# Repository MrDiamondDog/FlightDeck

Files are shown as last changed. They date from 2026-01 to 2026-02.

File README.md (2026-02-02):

# FlightDeck

Show your overhead flights in a nice and large LED matrix! Perfect addition to any room, especially to those nearby airports.

Additionally, the matrix will be able to display whatever you want in sleep/home states (when there are no flights), all customizable via a webserver hosted on the ESP, including displaying custom APIs!

I've seen a couple projects like this, and thought it would provide some nice experience to make my own, and it fits perfectly for Hack Club's Blueprint YSWS!

I haven't looked at any other similar projects, I want to build my own without copying others.

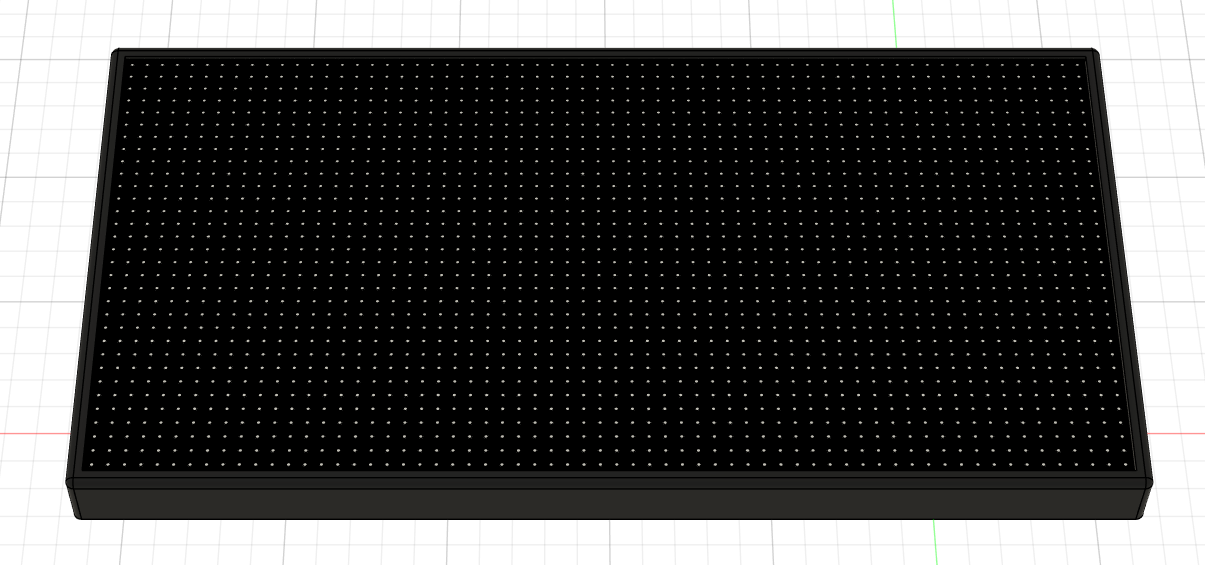
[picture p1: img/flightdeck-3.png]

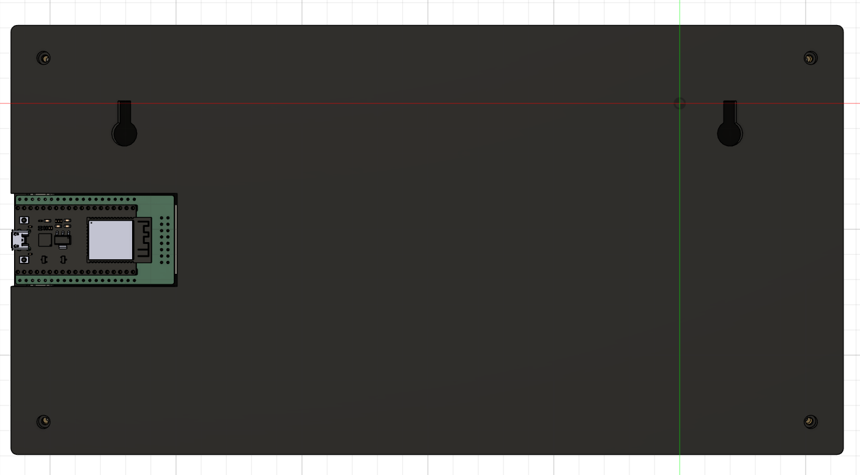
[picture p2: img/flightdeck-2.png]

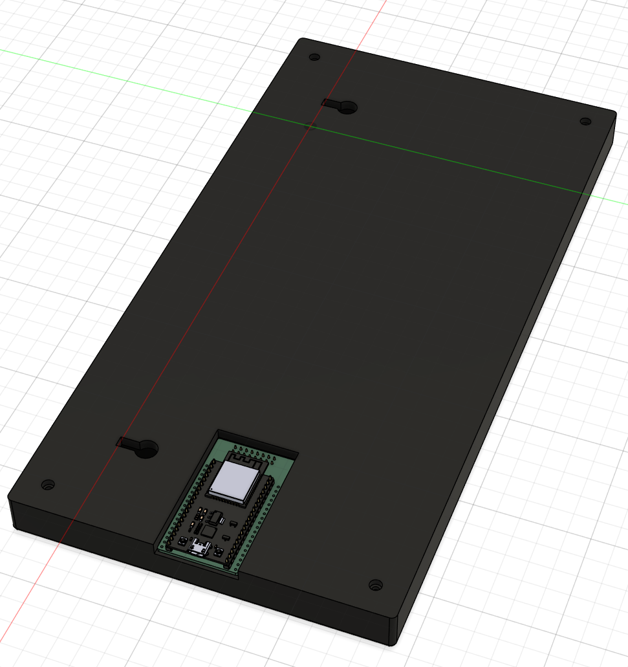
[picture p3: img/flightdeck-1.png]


## Hardware

A custom PCB is required for this project to connect the ESP dev board to the LED matrix.
All the gerber and KiCad files are in the `pcb` folder, and should run you about $5 on JLCPCB.

The rest of the hardware falls around $35 total on Aliexpress. See the [BOM](BOM) below.

- 64x32 RGB LED Matrix, 5mm pitch, 320x160mm ([Aliexpress](https://www.aliexpress.us/item/2251832185365664.html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))
- ESP32-DevKitC V4 Devboard ([Aliexpress](https://www.aliexpress.us/item/3256808703088919.html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))
- 2x8 Through-hole Female Pin Socket ([Aliexpress](https://www.aliexpress.us/item/3256803911413457.html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)) (only available in 10 pack) 
- 2.1mm Terminal Block Adapter ([Aliexpress](https://www.aliexpress.us/item/3256806569458868.html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](https://www.aliexpress.us/item/3256806079081322.html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))) (only in 5 pack)
- 5V 4A Barrel Jack Power Supply ([Aliexpress](https://www.aliexpress.us/item/3256807146253605.html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](https://www.aliexpress.us/item/3256806800927492.html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)))

### PCB

The PCB is pretty simple, just a bunch of holes for the ESP and HUB75 connector. 
There are extra holes along the ESP in case of emergency jumper wiring.

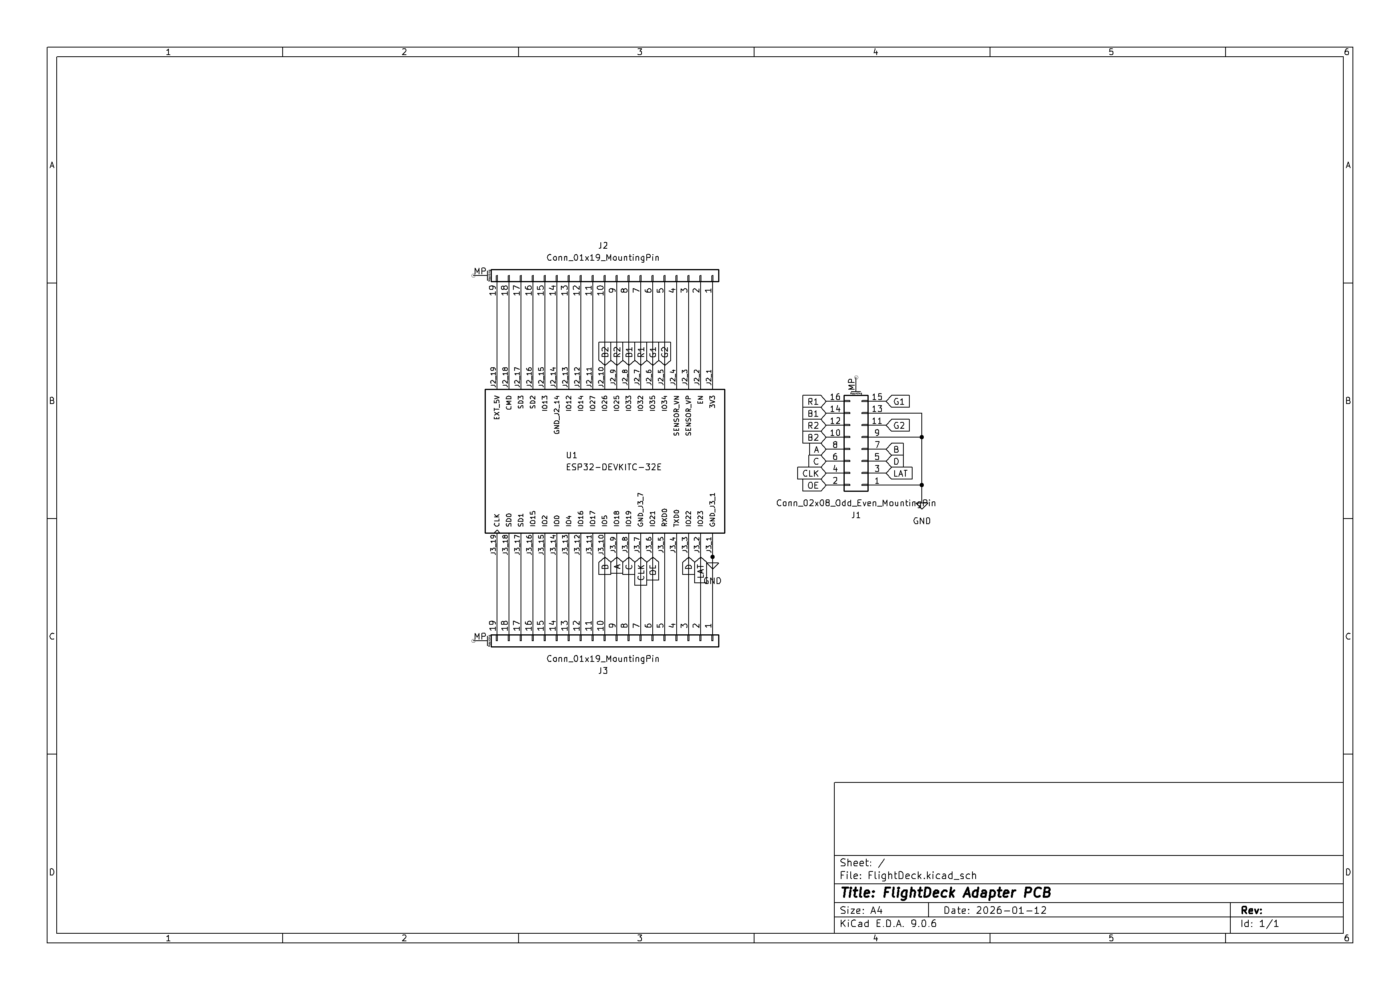
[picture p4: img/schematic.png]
PCB Schematic

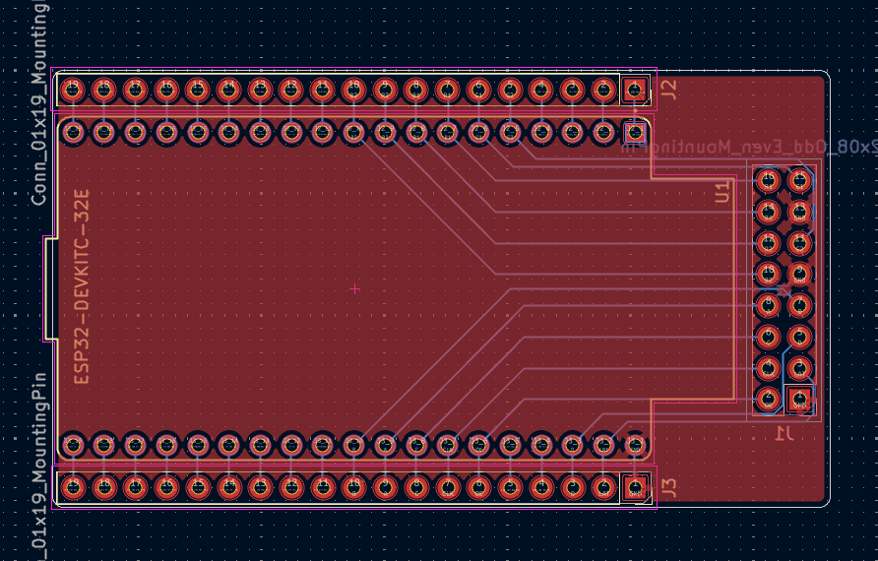
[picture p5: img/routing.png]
PCB Routing


### Wiring

1. Solder the dev board into the PCB. The PCB should have silkscreen text where you are putting the board. The USB should be hanging off the edge slightly.
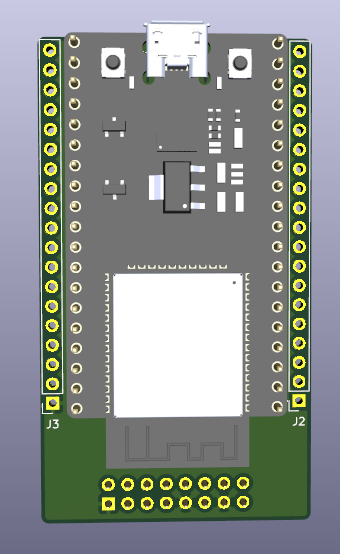
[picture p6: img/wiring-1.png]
Dev Board

2. Solder the pin connectors on the BACK of the PCB (opposite side of the dev board)
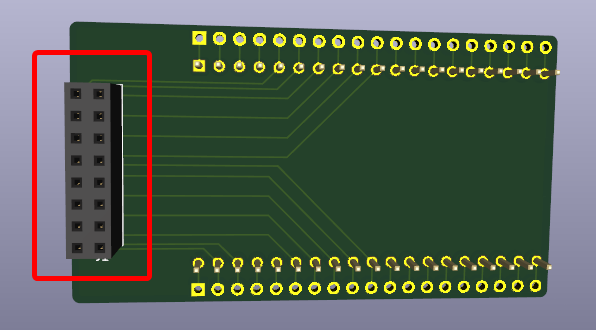
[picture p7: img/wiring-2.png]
Pin Connectors

3. Insert the PCB into the back of the LED matrix, making sure that the one you are plugging into is the INPUT (on the left), not the OUTPUT connector.
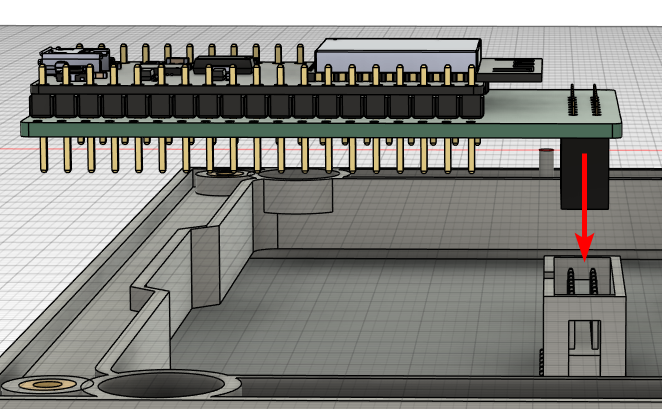
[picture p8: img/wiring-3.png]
Matrix

4. Connect the included power cables to the back of the LED matrix, then plug the U shaped ends into the (female) terminal block adapters, like so
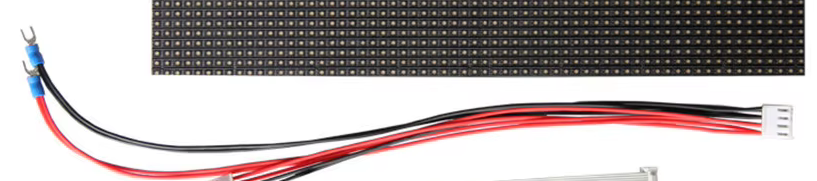
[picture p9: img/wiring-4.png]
Wires

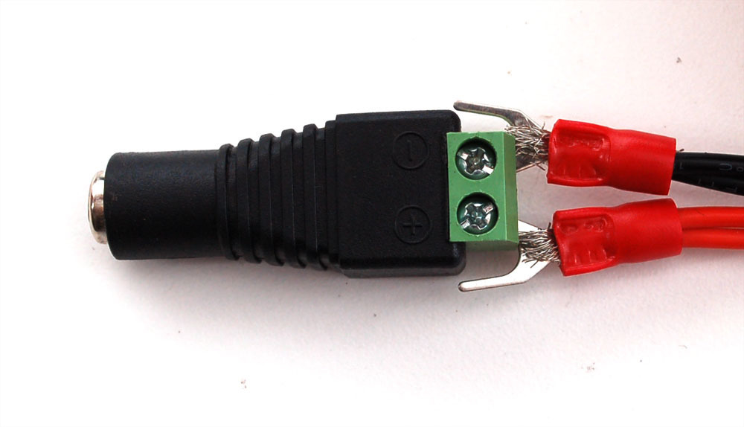
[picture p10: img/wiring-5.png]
Plug into adapter

5. Plug in your power supply to the adapter
6. Plug in micro USB to the esp

## Firmware

Programmed in CircuitPython, using the https://airlabs.co/ free live flight API. You may have to send them an email to get access. 

Make sure to rename the `settings.example.toml` file to `settings.toml` and fill in all the values.

TODO: There will be a webserver to customize the panel with, including custom sleep/home screens and custom API connections.

## BOM

**Please note: some of these items are only available in packs of 10 or 5, I could not find a cheaper alternative.**

| Name |Description | Link | Cost | Quantity | Total Price |
| ---- | --- | --- | --- | --- | --- |
| Factory P5 Indoor 320mmx160mm 16 Scan SMD Full Color Module 64x32 Pixels Dot Matrix Panel Video Screen Board | 64x32 LED Matrix | [Aliexpress](https://www.aliexpress.us/item/2251832185365664.html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) | $11.69 | 1 | $11.69 |
| ESP32-DevKitC V4 core board ESP32 development board All Types with ESP32-WROOM-32 32D 32U 32E WIFI+Bluetooth IoT NodeMCU-32 | ESP32-DevKitC V4 Dev Board | [Aliexpress](https://www.aliexpress.us/item/3256808703088919.html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) | $7.78 | 1 | $7.78 |
| 10PCS 2.54mm Double Row Female Long Pin 11mm Breakaway PCB Board Pin Header Socket Connector 2x8 pins | 2x8 Through-hole Female Pin Sockets (10pcs) | [Aliexpress](https://www.aliexpress.us/item/3256803911413457.html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) | $3.85 | 1 | $3.85 |
| 5pcs DC 12V Female And Male Connectors 5.5x2.1mm Power Plug Adapter Jacks Sockets For Signal Color LED Strip Light CCTV Camera | 2.1mm Terminal Block Adapter (5pcs) | [Aliexpress](https://www.aliexpress.us/item/3256806079081322.html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) | $1.83 | 1 | $1.83 |
| DC 5V LED Power Supply AC 110V~220V Lighting Transformer 4A Power Adapters For CCTV Camera Router | 5V 4A Power Supply | [Aliexpress](https://www.aliexpress.us/item/3256806800927492.html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) | $5.18 | 1 | $5.18 |
| JLCPCB Order (5 PCBs) | PCB |  | $3.12 | 1 | $3.12 |
| Total |  |  |  |  | $37.13 |

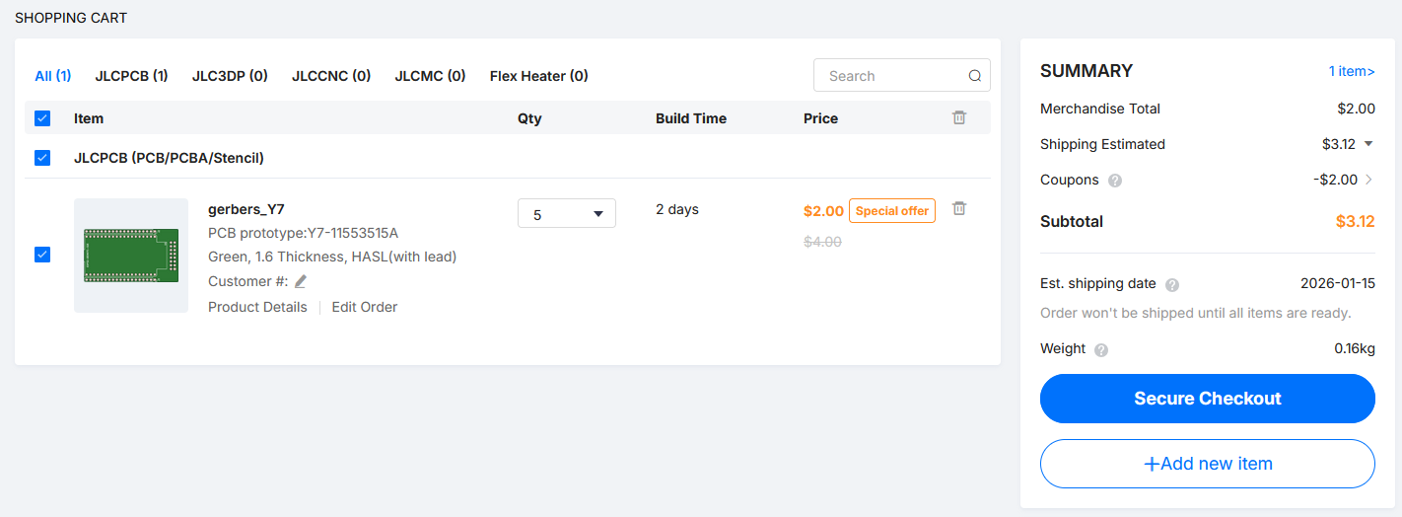
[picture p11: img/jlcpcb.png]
JLCPCB Cart


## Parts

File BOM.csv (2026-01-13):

Name | Description | Link | Cost | Amount | Total
Factory P5 Indoor 320mmx160mm 16 Scan SMD Full Color Module 64x32 Pixels Dot Matrix Panel Video Screen Board | 64x32 LED Matrix | https://www.aliexpress.us/item/2251832185365664.html?mp=1 | $11.69 | 1 | $11.69
ESP32-DevKitC V4 core board ESP32 development board All Types with ESP32-WROOM-32 32D 32U 32E WIFI+Bluetooth IoT NodeMCU-32 | ESP32-DevKitC V4 Dev Board | https://www.aliexpress.us/item/3256808703088919.html?mp=1 | $7.78 | 1 | $7.78
10PCS 2.54mm Double Row Female Long Pin 11mm Breakaway PCB Board Pin Header Socket Connector 2x8 pins | 2x8 Through-hole Female Pin Sockets (10pcs) | https://www.aliexpress.us/item/3256803911413457.html?mp=1 | $3.85 | 1 | $3.85
5pcs DC 12V Female And Male Connectors 5.5x2.1mm Power Plug Adapter Jacks Sockets For Signal Color LED Strip Light CCTV Camera | 2.1mm Terminal Block Adapter (5pcs) | https://www.aliexpress.us/item/3256806079081322.html | $1.83 | 1 | $1.83
DC 5V LED Power Supply AC 110V~220V Lighting Transformer 4A Power Adapters For CCTV Camera Router | 5V 4A Power Supply | https://www.aliexpress.us/item/3256806800927492.html | $5.18 | 1 | $5.18
JLCPCB Order (5 PCBs) | PCB |  | $3.12 | 1 | $3.12

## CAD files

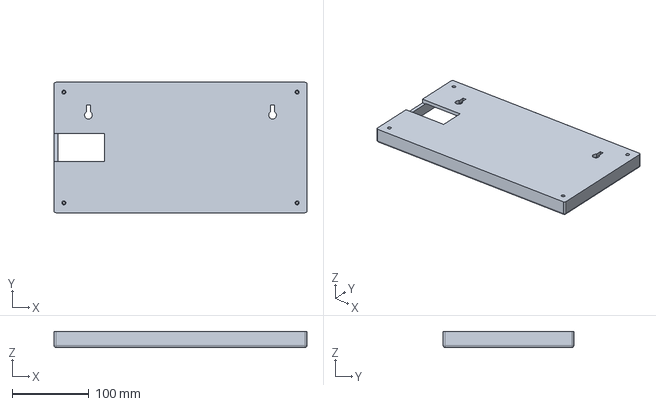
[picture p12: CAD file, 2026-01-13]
cad/FlightDeck.step
330.5 x 170.5 x 21.0 mm

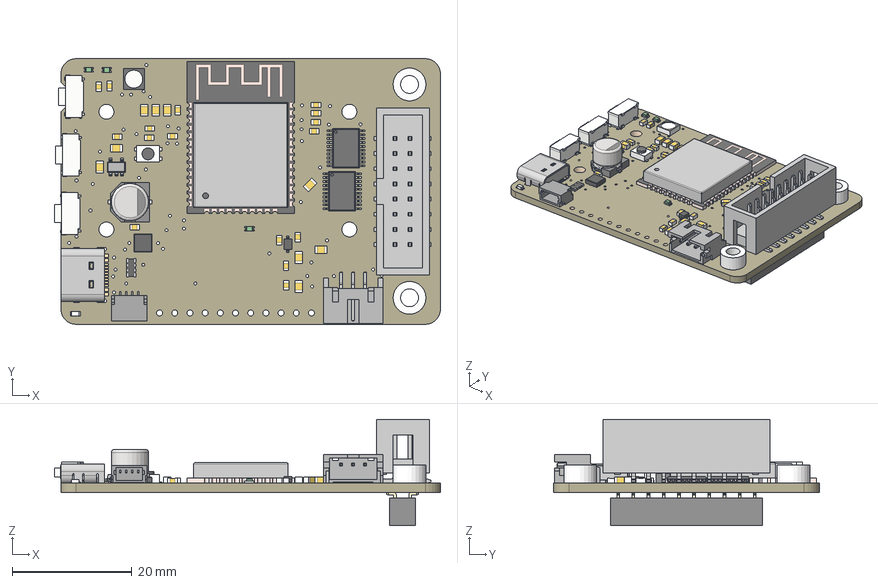
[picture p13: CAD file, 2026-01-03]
cad/parts/5778 Matrix Portal S3.step
64.6 x 44.5 x 17.8 mm
Board
RED x 3
10uF x 9
AP2112K-3.3
WS2812B_3535FULL
10K x 16
5.1K Pack
USB TYPE C
TL3330AF260QG x 3
100uF/6.3V
74AHCT245 x 2
SEWTAP_SMTNUTM3 x 2
STEMMA_I2C_QT
JST PH 3
3.6V
LIS3DHTR
KMR2
ESP32-S3-WROOM
ALS-PT19
2x8_SMT_IDC
2x10_SMT_F

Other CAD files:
cad/FlightDeck_Base.step
cad/FlightDeck_Base.f3d

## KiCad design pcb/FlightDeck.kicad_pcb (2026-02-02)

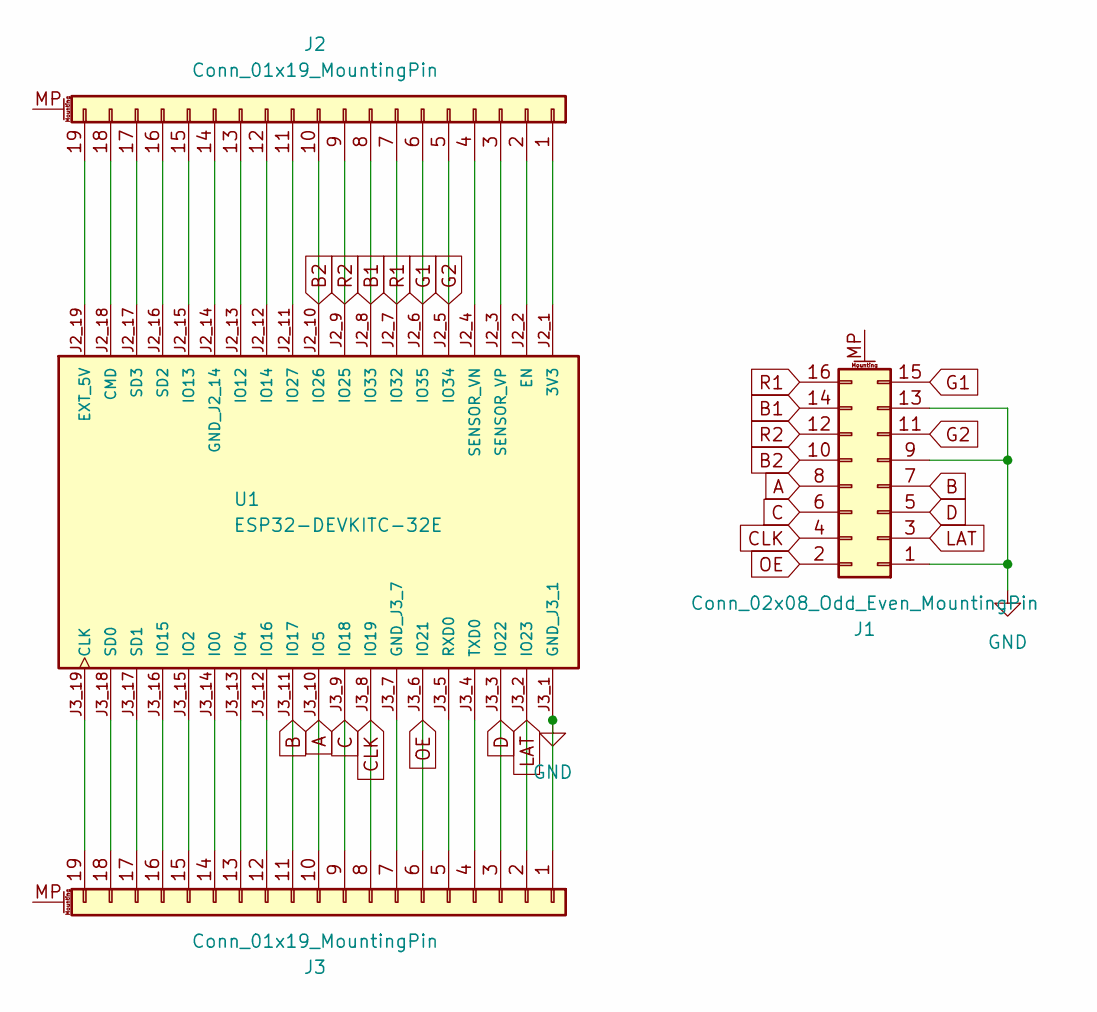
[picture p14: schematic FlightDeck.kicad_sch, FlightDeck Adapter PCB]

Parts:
J1: Conn_02x08_Odd_Even_MountingPin; PinSocket_2x08_P2.54mm_Vertical
J2, J3: Conn_01x19_MountingPin; PinSocket_1x19_P2.54mm_Vertical
U1: ESP32-DEVKITC-32E; MODULE_ESP32-DEVKITC-32E; PARTREV 1.4

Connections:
A: J1.8, J3.10, U1.J3_10 (IO5)
B: J1.7, J3.11, U1.J3_11 (IO17)
B1: J1.14, J2.8, U1.J2_8 (IO33)
B2: J1.10, J2.10, U1.J2_10 (IO26)
C: J1.6, J3.9, U1.J3_9 (IO18)
CLK: J1.4, J3.8, U1.J3_8 (IO19)
D: J1.5, J3.3, U1.J3_3 (IO22)
G1: J1.15, J2.6, U1.J2_6 (IO35)
G2: J1.11, J2.5, U1.J2_5 (IO34)
GND: J1.1, J1.9, J1.13, J3.1, U1.J3_1 (GND_J3_1)
LAT: J1.3, J3.2, U1.J3_2 (IO23)
unnamed: J2.1, U1.J2_1 (3V3)
unnamed: J2.2, U1.J2_2 (EN)
unnamed: J2.3, U1.J2_3 (SENSOR_VP)
unnamed: J2.4, U1.J2_4 (SENSOR_VN)
unnamed: J2.11, U1.J2_11 (IO27)
unnamed: J2.12, U1.J2_12 (IO14)
unnamed: J2.13, U1.J2_13 (IO12)
unnamed: J2.14, U1.J2_14 (GND_J2_14)
unnamed: J2.15, U1.J2_15 (IO13)
unnamed: J2.16, U1.J2_16 (SD2)
unnamed: J2.17, U1.J2_17 (SD3)
unnamed: J2.18, U1.J2_18 (CMD)
unnamed: J2.19, U1.J2_19 (EXT_5V)
unnamed: J3.4, U1.J3_4 (TXD0)
unnamed: J3.5, U1.J3_5 (RXD0)
unnamed: J3.7, U1.J3_7 (GND_J3_7)
unnamed: J3.12, U1.J3_12 (IO16)
unnamed: J3.13, U1.J3_13 (IO4)
unnamed: J3.14, U1.J3_14 (IO0)
unnamed: J3.15, U1.J3_15 (IO2)
unnamed: J3.16, U1.J3_16 (IO15)
unnamed: J3.17, U1.J3_17 (SD1)
unnamed: J3.18, U1.J3_18 (SD0)
unnamed: J3.19, U1.J3_19 (CLK)
OE: J1.2, J3.6, U1.J3_6 (IO21)
R1: J1.16, J2.7, U1.J2_7 (IO32)
R2: J1.12, J2.9, U1.J2_9 (IO25)

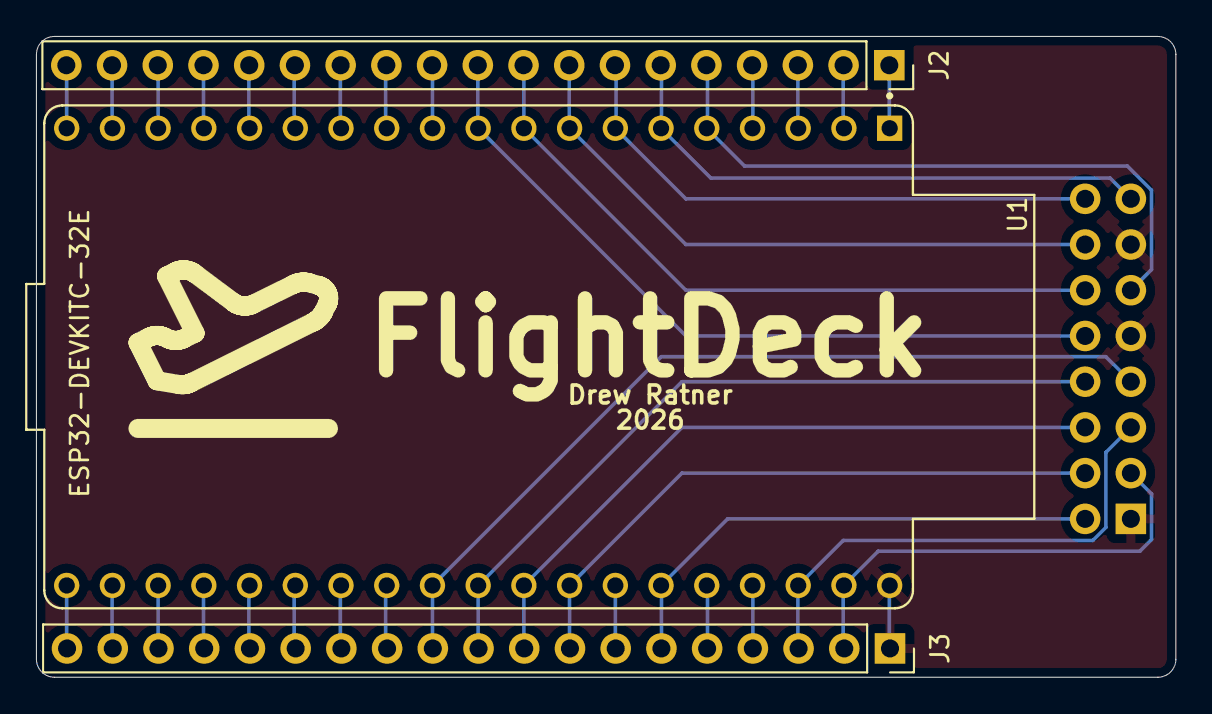
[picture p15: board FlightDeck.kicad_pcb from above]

Board: 2 copper layers, 63.3 x 35.6 mm, 4 parts (1 on the bottom side), 38 nets.

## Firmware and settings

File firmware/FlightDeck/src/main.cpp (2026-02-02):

#include "ESP32-HUB75-MatrixPanel-I2S-DMA.h"
#include <Fonts/TomThumb.h>

#include "img.hpp"

#define R1 32
#define G1 14
#define BL1 33
#define R2 25
#define G2 12
#define BL2 26
#define CH_A 5
#define CH_B 17
#define CH_C 18
#define CH_D 22
#define CH_E -1 // doesnt exist
#define CLK 19
#define LAT 23
#define OE 21

// uint8_t rgbPins[]  = {R1, G1, BL1, R2, G2, BL2};
// uint8_t addrPins[] = {CH_A, CH_B, CH_C, CH_D};
// uint8_t clockPin   = CLK;
// uint8_t latchPin   = LAT;
// uint8_t oePin      = OE;

MatrixPanel_I2S_DMA *disp = nullptr;

void disp_flight(const uint16_t img[], char* number, char* aircraft, char* speed, char* altitude, char* from, char* to, char* reg) {
  disp->drawRGBBitmap(0, 0, img, 16, 16);

  disp->setCursor(17, 5);
  disp->print(number);

  disp->setCursor(17, 11);
  disp->print(aircraft);

  disp->setCursor(17, 17);
  disp->print(reg);

  disp->setCursor(0, 23);
  disp->print((std::string(from) + " -> " + std::string(to)).c_str());

  disp->setCursor(0, 29);
  disp->print((std::string(speed) + " - " + std::string(altitude)).c_str());
}

void setup() {
  HUB75_I2S_CFG::i2s_pins _pins={R1, G1, BL1, R2, G2, BL2, CH_A, CH_B, CH_C, CH_D, CH_E, LAT, OE, CLK};
  HUB75_I2S_CFG mxconfig(64, 32, 1, _pins);

  disp = new MatrixPanel_I2S_DMA(mxconfig);
  disp->begin();
  disp->setBrightness8(20);
  disp->clearScreen();
  disp->setFont(&TomThumb);

  disp_flight(epd_bitmap_Unknown, "UA2414", "B737", "250mph", "30000ft", "DEN", "HCK", "N1234B");
}

void loop() {

}

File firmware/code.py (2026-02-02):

# https://learn.adafruit.com/rgb-led-matrices-matrix-panels-with-circuitpython/
import board
import os
import time
import terminalio
import displayio
import framebufferio
import wifi
import rgbmatrix
import adafruit_requests
import adafruit_connection_manager
import adafruit_display_text.label

# Get WiFi details, ensure these are setup in settings.toml
ssid = os.getenv("CIRCUITPY_WIFI_SSID")
password = os.getenv("CIRCUITPY_WIFI_PASSWORD")

# Initalize Wifi, Socket Pool, Request Session
pool = adafruit_connection_manager.get_radio_socketpool(wifi.radio)
ssl_context = adafruit_connection_manager.get_radio_ssl_context(wifi.radio)
requests = adafruit_requests.Session(pool, ssl_context)
rssi = wifi.radio.ap_info.rssi

print(f"Connecting to {ssid}...")
print(f"Signal Strength: {rssi}")
try:
    # Connect to the Wi-Fi network
    wifi.radio.connect(ssid, password)
except OSError as e:
    print(f"OSError: {e}")
print("Wifi Connected")

print("Initializing display")

displayio.release_displays()
matrix = rgbmatrix.RGBMatrix(
    width=64, height=32, bit_depth=1,
    rgb_pins=[board.D6, board.D5, board.D9, board.D11, board.D10, board.D12],
    addr_pins=[board.A5, board.A4, board.A3, board.A2],
    clock_pin=board.D13, latch_pin=board.D0, output_enable_pin=board.D1)

# Associate the RGB matrix with a Display so that we can use displayio features
display = framebufferio.FramebufferDisplay(matrix, auto_refresh=False)

network = matrix.network
graphics = matrix.graphics

g = displayio.Group()

# Add a box on screen
box = displayio.Shape(64, 32)
box_bitmap = displayio.Bitmap(64, 32, 1)
box_palette = displayio.Palette(1)
box_palette[0] = 0x000000  # Black
box_sprite = displayio.TileGrid(box_bitmap, pixel_shader=box_palette, x=0, y=0)
g.append(box_sprite)

display.root_group = g

# Uses arlabs.co API
# flightsApi = "https://airlabs.co/api/v9/flights"
# headers = {"user-agent": "FlightDeck/1.0.0"}

# apiKey = os.getenv("AIRLABS_API_KEY")

# minLat = min(os.getenv("MIN_LAT"), os.getenv("MAX_LAT"))
# minLon = min(os.getenv("MIN_LON"), os.getenv("MAX_LON"))
# maxLat = max(os.getenv("MIN_LAT"), os.getenv("MAX_LAT"))
# maxLon = max(os.getenv("MIN_LON"), os.getenv("MAX_LON"))

# def get_nearby_flights():
#     with requests.get(f"{flightsApi}?api_key={apiKey}&bbox={minLat},{minLon},{maxLat},{maxLon}", headers=headers) as response:
#         json_data = response.json().response[0]
#         data = {
#             "altitude": json_data["alt"],
#             "speed": json_data["speed"],
#             "number": json_data["flight_icao"],
#             "aircraft": json_data["aircraft_icao"],
#             "fromCode": json_data["dep_iata"],
#             "toCode": json_data["arr_iata"],
#             "registration": json_data["reg_number"]
#         }
    
#     return data

# def text(text, x, y, color = 0xffffff):
#     line = adafruit_display_text.label.Label(
#         terminalio.FONT,
#         color=color,
#         text=text,
#     )
#     line.x = x
#     line.y = y

#     g.append(line)

#     return line

# flightNum = text("", 0, 0)
# flightAircraft = text("", 0, 6)
# flightRoute = text("", 0, 12)
# flightAltitude = text("", 0, 18)
# flightRegistration = text("", 0, 24)

# display.root_group = g

# while True:
#     time.sleep(30)

#     data = get_nearby_flights()

#     if not data:
#         flightNum.text = ""
#         flightAircraft.text = ""
#         flightRoute.text = ""
#         flightAltitude.text = ""
#         flightRegistration.text = ""
#         pass

#     flightNum.text = data.number
#     flightAircraft.text = data.aircraft
#     flightRoute.text = f"{data.fromCode}-{data.toCode}"
#     flightAltitude.text = f"{data.altitude}ft"
#     flightRegistration.text = data.registration

#     pass

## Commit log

2026-01-04 Update CAD and images with mounting holes
    [FlightDeck.step]
2026-01-13 New PCB
    [FlightDeck.kicad_pcb, FlightDeck.kicad_sch]
2026-01-13 New PCB and hardware details
    [FlightDeck.kicad_pcb, FlightDeck.kicad_sch]
2026-01-13 Update BOM
2026-01-13 CAD Upload
    [FlightDeck.step]
2026-01-13 Update readme with JLCPCB cart image and accurate PCB price
2026-01-13 Price Optimization
    [BOM.csv]
2026-01-13 Update PCB with silkscreen
    [FlightDeck.kicad_pcb]
2026-02-02 Updated firmware to not use circuitpython
    [FlightDeck.kicad_pcb, FlightDeck.kicad_sch]
